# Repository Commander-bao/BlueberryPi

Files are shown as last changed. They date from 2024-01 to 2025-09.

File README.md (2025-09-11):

<h1 align="center">造“派”计划</h1>
<div align="center">








</div>

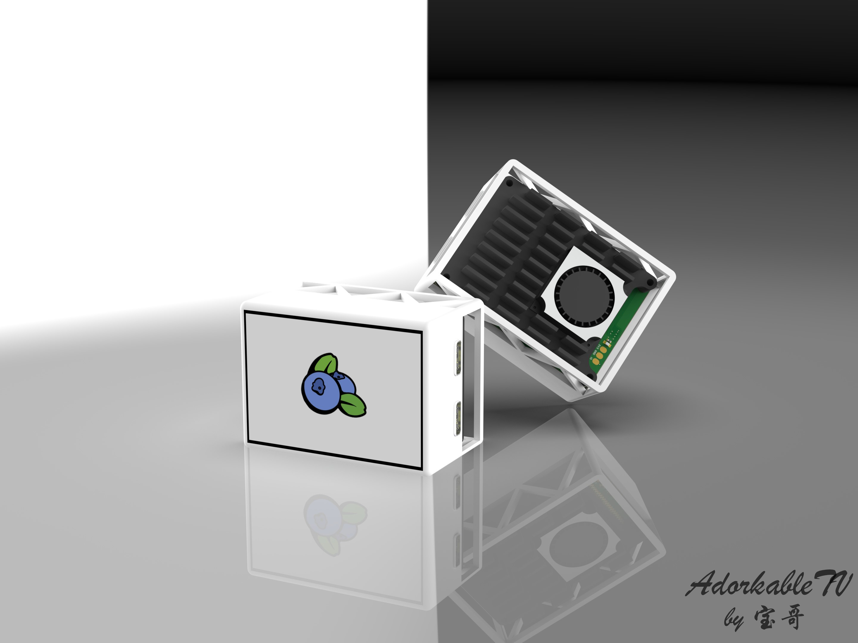
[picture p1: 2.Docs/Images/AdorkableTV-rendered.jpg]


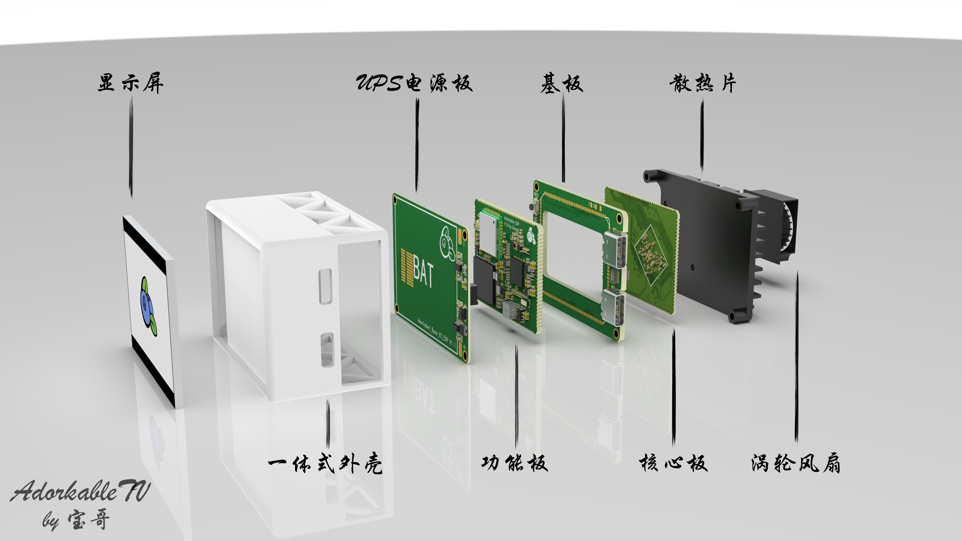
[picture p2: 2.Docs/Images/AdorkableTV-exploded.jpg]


从左至右分别为AdorkableTV、BlueberryPi 1、BlueberryPi-Core


## 0.关于本项目

当我看到树莓派4b的那一刻起，我就对这个卡片大小的单板计算机深深的吸引，漂亮的布局、完整的功能...我能不能自己也做一个呢？  

这就是造“派”计划的由来。本人通过四处搜寻资料以及在[这个项目](https://oshwhub.com/logicworld/h6_board)的指引下，成功设计出**BlueberryPi 1**，又在自学Altium Designer后画了它的核心板**BlueberryPi-Core**。在蓝莓派成功后又以立创泰山派为原型，重构软硬件设计了**AdorkableTV**。  

我的“蓝莓派”是一板成功的，但是也免不了这一路上的曲折，中途因为短路等各种原因焊废了好几块板子，导致我一度怀疑人生。好在功夫不负有心人，当电源小灯亮起来，屏幕上出现Ubuntu界面的时候，我知道我成功了。  

## 1.硬件打样说明

电路板Gerber文件为Hardware文件夹下的zip压缩包，可以直接上传到嘉立创平台进行打样。  

- BlueberryPi 1、Adorkable_Base、Adorkable_EXP请使用嘉立创eda（专业版）打开。  

- BlueberryPi-Core、Adorkable_Core请使用Altium Designer打开。  

BlueberryPi 1请使用嘉立创3313阻抗，1.6mm板厚。  

Adorkabe_Core、Adorkable_EXP请使用嘉立创3313阻抗，1.2mm板厚；Adorkable_Base、Adorkable_Base_V2请使用嘉立创3313阻抗，1.6mm板厚。以上均选用免费20%阻抗管控，有半孔的请使用四边半孔工艺。  

Adorkable_Base_V2_EXP为0.8mm板厚。

## 2.镜像烧录说明

BlueberryPi 1目前使用的是香橙派官方的镜像文件[这是网址](http://www.orangepi.cn/html/hardWare/computerAndMicrocontrollers/details/Orange-Pi-3-LTS.html)（蓝莓版镜像待移植）。下载好镜像后可以使用balenaEtcher将镜像烧录至TF卡中。  

AdorkableTV目前使用的是我定制的Ubuntu镜像，有xfce和xfce-full两个版本，可以从[百度网盘](https://pan.baidu.com/s/1jsw3okSnh8e9oXT7oVLvJg?pwd=v6qs)中下载使用。下载好镜像后使用瑞芯微烧录工具下载到板载EMMC中。

如果要为立创泰山派定制Ubuntu镜像，请参考Script文件夹下的README文档制作文件系统，将官方提供的镜像文件通过RKDevTool解包后替换boot.img和rootfs.img（建议修改分区表文件，扩大rootfs分区容量），最后通过RKDevTool文件夹下的打包脚本打包。也可以从百度网盘下载使用我移植的蓝莓版Ubuntu20.04桌面系统，Bootloader和Kernel已经放在了对应的文件夹下，大家可以根据需要下载。下载好镜像后可以使用balenaEtcher将镜像烧录至TF卡中，也可使用瑞芯微烧录工具下载到板载EMMC中。 

## 3.硬件使用说明

- BlueberryPi 1使用说明：将烧录好镜像文件的TF卡插入TF卡槽内，micro-usb接通5V-2A的电源后即可通过串口/HDMI连接使用。  

- BlueberryPi-Core使用说明：参考全志官方/香橙派/BlueberryPi 1中的原理图，绘制底板后，将BlueberryPi-Core贴至底板上使用（待测试）。  

- AdorkableTV使用说明：绘制扩展底板，将核心板和功能板分别贴至底板两面，烧录镜像至TF卡或EMMC中使用。

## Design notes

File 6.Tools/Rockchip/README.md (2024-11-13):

# 造“派”计划
## 工具说明
DriverAssistant —— 瑞芯微驱动安装助手  
Linux_Pack_Firmware —— Linux镜像打包工具  
RKDevTool_Release —— 瑞芯微烧录工具

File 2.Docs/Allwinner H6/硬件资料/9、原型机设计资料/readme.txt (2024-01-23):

H6_PRO_DDR3_1V1 是H6内部原型机的对应的原理图和PCB
注：PCB可以再设计中参考下，但原理图建议还是使用标案原理图设计（该原型机原理图前期设计存在大部分冗余设计和不合理设计，仅供参考，不建议直接使用）

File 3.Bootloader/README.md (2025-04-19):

# 造“派”计划

## 文件夹说明

Rockchip RK3566 tspi文件夹下为立创泰山派编译好的U-boot，详细内容请查看7.Script/Ubuntu文件夹内的README文档  

AdorkableTV文件夹下为AdorkableTV专用的U-boot

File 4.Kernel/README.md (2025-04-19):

# 造“派”计划

## 文件夹说明

Rockchip RK3566 tspi文件夹下为立创泰山派编译好的Kernel，详细内容请查看7.Script/Ubuntu文件夹内的README文档  

AdorkableTV文件夹下为AdorkableTV专用的Kernel以及部分修改过的内核源码

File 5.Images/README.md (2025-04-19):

# 造“派”计划
## 蓝莓版Ubuntu镜像
通过网盘分享的文件：BlueberryPi  
链接: https://pan.baidu.com/s/1jsw3okSnh8e9oXT7oVLvJg?pwd=v6qs 提取码: v6qs  

自己构建的方法请查看7.Script/Ubuntu文件夹内的README文档

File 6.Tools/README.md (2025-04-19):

# 造“派”计划

## 文件夹说明

Rockchip文件夹下为瑞芯微官方提供的部分工具

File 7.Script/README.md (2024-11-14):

# 造“派”计划

## 文件夹说明

Ubuntu文件夹下为Ubuntu根文件系统的构建脚本，详细内容请查看Ubuntu文件夹内的README文档

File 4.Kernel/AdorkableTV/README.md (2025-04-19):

# 造“派”计划
编译方法参考立创泰山派的教程：https://wiki.lckfb.com/zh-hans/tspi-rk3566/sdk-compilation/linux-compilation.html  

boot.img文件为编译好的kernel  

SDK文件夹内为基于立创泰山派修改过的部分SDK源码

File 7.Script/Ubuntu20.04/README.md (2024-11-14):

# 造“派”计划

## 简介

为瑞芯微系列芯片移植Ubuntu文件系统的脚本，魔改自鲁班猫（ https://github.com/LubanCat/ubuntu ）

## 适用板卡

- 使用RK3566处理器的板卡
- 使用RK3568处理器的板卡
- 使用RK3588处理器的板卡

## 安装依赖

推荐使用Ubuntu20.04及以上版本主机构建根文件系统

```
sudo apt-get install binfmt-support qemu-user-static
sudo dpkg -i ubuntu-build-service/packages/*
sudo apt-get install -f
```

## 构建 Ubuntu20.04镜像（仅支持64bit）

- lite：控制台版，无桌面
- xfce：桌面版，使用xfce桌面套件
- xfce-full：桌面版，使用xfce桌面套件+更多推荐软件包
- gnome：桌面版，使用gnome桌面套件
- gnome-full：桌面版，使用gnome桌面套件+更多推荐软件包

#### step1.构建基础 Ubuntu 系统。

```
# 运行以下脚本，根据提示选择要构建的版本
./mk-base-ubuntu.sh
```
#### step2.添加 rk overlay 层,并打包ubuntu-rootfs镜像

```
# 运行以下脚本，根据提示选择要构建处理器版本和ubuntu的版本
./mk-ubuntu-rootfs.sh
```

## 定制化说明

### 1.开机桌面壁纸设置：  

默认桌面壁纸为蓝莓派logo  

如要更改，请在/usr/share/xfce4/backdrops/目录下添加壁纸图片，并将mk-ubuntu-rootfs.sh文件下的blueberry_wallpaper.png替换为自己的壁纸图片

### 2.开机终端输出logo设置：  

默认输出图像为蓝莓派logo和BlueberryPi  

如要更改，请在/overlay/etc/update-motd.d/目录下更改00-header和10-help-text文件

### 3.主机名设置：  

默认主机名为BlueberryPi  

如要更改，请在mk-base-ubuntu.sh将`HOST=`后面的内容替换成你设置的主机名

### 4.用户名密码设置：  

默认用户名为blueberry，密码为pi；超级用户root，密码为root  

如要更改，请在mk-base-ubuntu.sh将全部`blueberry`换成你设置的用户名

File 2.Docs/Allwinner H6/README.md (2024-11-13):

# 造“派”计划
## 全志H6资料下载链接
> 百度网盘：[全志科技 Allwinnertech H6 SoC 方案级参考指南]  
> https://pan.baidu.com/s/1z1sYXkeuYGrHgMcpjg0E-Q?pwd=2dmb 提取码：2dmb

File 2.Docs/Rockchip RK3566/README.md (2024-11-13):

# 造“派”计划
## 泰山派参考资料
> 百度网盘：https://pan.baidu.com/s/18B0r1MrG7kCVOC_toQY16A?pwd=v5fz 提取码：v5fz  
> 夸克网盘：https://pan.quark.cn/s/b4261bc38992 提取码：qNT3
## 泰山派SDK
> 百度网盘：https://pan.baidu.com/s/1frwvXAGoHnPuEoVkOJ-2pA?pwd=jf9v 提取码: jf9v  
> 夸克网盘：https://pan.quark.cn/s/7b0fdc54c332 提取码：2fS5
## 泰山派系统镜像
> 百度网盘：https://pan.baidu.com/s/1Mc7N6GKHTd2zJTfLsGBSqw?pwd=af1y 提取码: af1y  
> 夸克网盘：https://pan.quark.cn/s/3b5cf0e118bd 提取码：RyR4
## 泰山派开发工具
> 百度网盘：https://pan.baidu.com/s/1-gNeeTlJgmgm2x1DpDAdRQ?pwd=v72h 提取码: v72h  
> 夸克网盘：https://pan.quark.cn/s/8b7a1f409af1 提取码：yNRw

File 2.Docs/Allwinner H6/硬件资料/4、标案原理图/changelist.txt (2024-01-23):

changelist：
/*************************************2017-7-20*************************************/
SOC1页
1：sdio clk CC2电容 容值改为5PF

SOC2页
2：在GPU 和 SYS 滤波电容 添加10uf电容 CC62 22uf电容 CC63

3：删除OSC 24M晶振

4：VCC18-HDMI添加4.7UF 电容 CC61

POWER页
5：分离CLDO1 和 ALDO3 将ALDO3的电源分配给DDR4

6：删除SWIN 和 SWOUT的电容 CP14 CP15

7：修改DCXOVCCIO的供电为BLDO3

USB页
8：修改电阻RU3 为4.3K

AV页
9：优化了运放电路，删除了多余器件

HDMI页
10：修改5V到地ESD为电容CH2

11：删除电阻RH10 RH11，RH5 改为1K.

12：修改DDC_EN电路，删除CEC的控制

WIFI+BT页
13：sdio clk 添加上拉电阻RW49

14：添加电源说明表格

GMAC页
15：添加GMAC页
添加电源网络VCC3V3_MAC 和 PD口部分出线

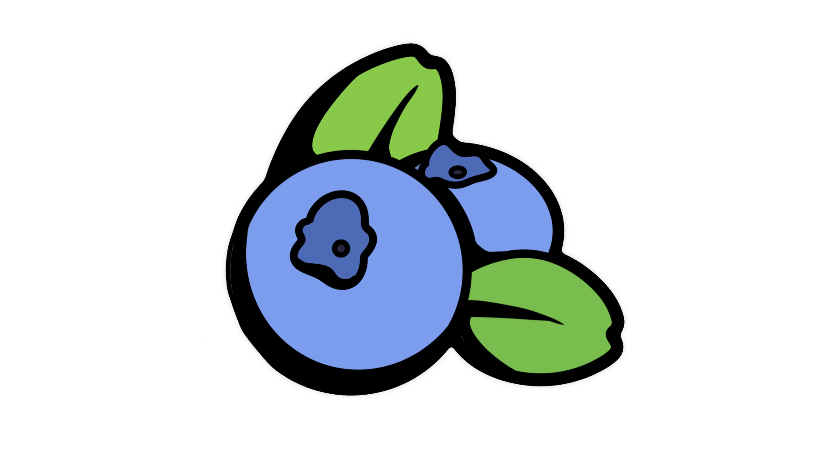
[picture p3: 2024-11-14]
7.Script/Ubuntu20.04/overlay/usr/share/xfce4/backdrops/blueberry_wallpaper.png

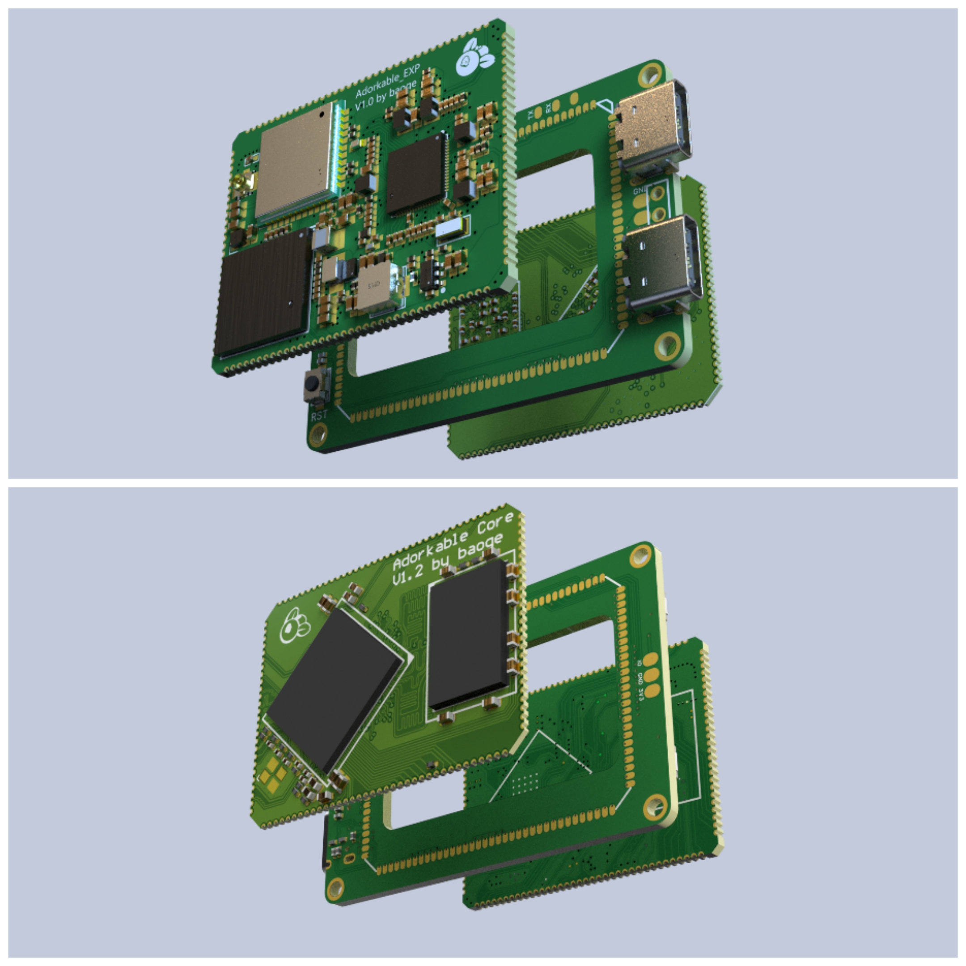
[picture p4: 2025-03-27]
2.Docs/Images/AdorkableTV.jpg

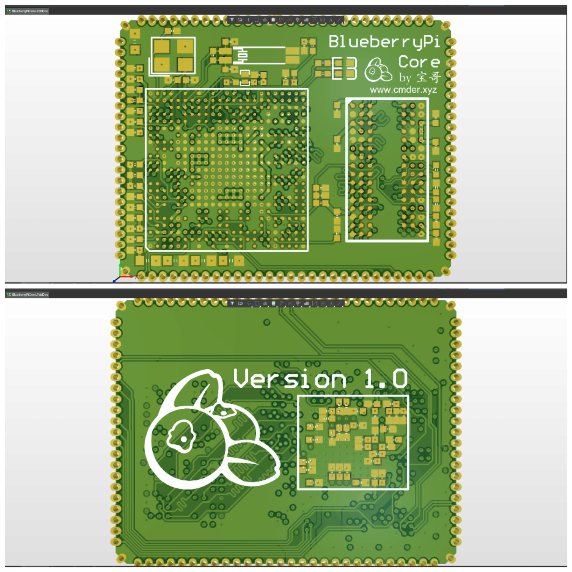
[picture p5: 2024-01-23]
2.Docs/Images/BlueberryPi-Core.jpg

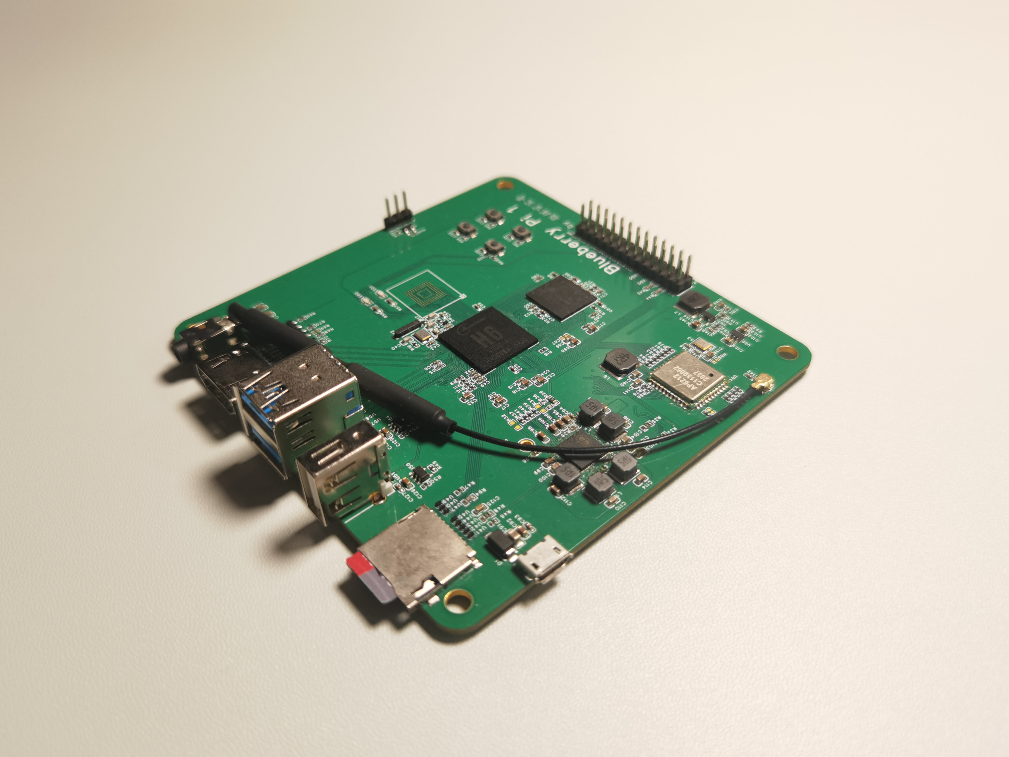
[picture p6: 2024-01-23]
2.Docs/Images/BlueberryPi 1.jpg

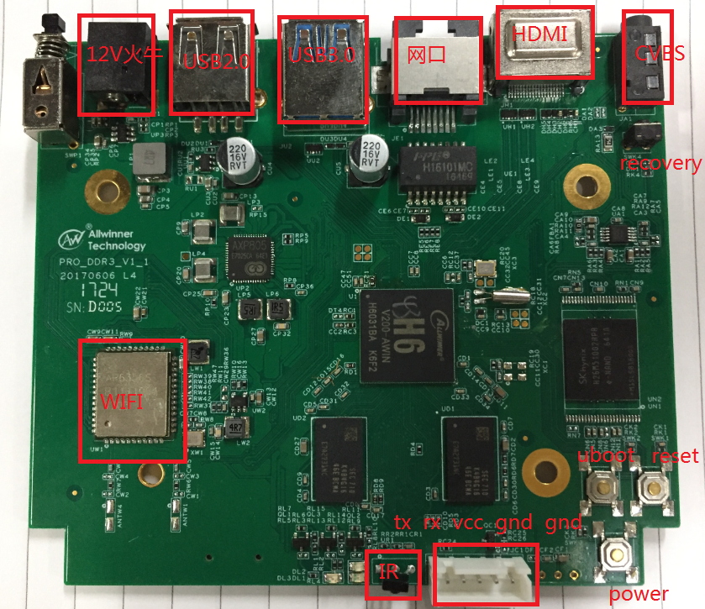
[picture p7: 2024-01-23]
2.Docs/Allwinner H6/硬件资料/8、DEMO板图示/原型机demo.PNG

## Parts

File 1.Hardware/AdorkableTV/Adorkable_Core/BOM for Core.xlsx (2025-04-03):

Comment | Description | Designator | Footprint | LibRef | Quantity | Value
C0402 | Capacitor | C1, C2, C51, C52, C53, C54, C55, C56, C62, C63, C64, C65, C66, C67, C68, C69, C70, C71, C72, C73, C74, C75, C76, C77, C82, C83, C84, C85, C86, C87, C88, C89, C90, C91, C92, C93, C94, C95, C96, C97, C98, C99 | CAP_0402 | Cap_0402 | 42 | 100nF
C0402 | Capacitor | C3, C4 | CAP_0402 | Cap_0402 | 2 | 12pF
C0201 | Capacitor | C5, C6, C7, C8, C9, C10, C12, C13, C15, C17, C18, C19, C20, C23, C24, C26, C28, C30, C31, C33, C34, C35, C38, C39, C40, C43, C46, C47, C48, C57, C104, C105, C106, C113, C118, C122 | CAP_0201 | Cap_0201 | 36 | 100nF
C0402 | Capacitor | C11, C14, C22, C25, C29, C61, C81 | CAP_0402 | Cap_0402 | 7 | 1uF
C0201 | Capacitor | C16, C32 | CAP_0201 | Cap_0201 | 2 | 1uF
C0402 | Capacitor | C21, C27, C36, C37, C41, C42, C100, C107, C108, C109, C114 | CAP_0402 | Cap_0402 | 11 | 4.7uF
C0402 | Capacitor | C44, C45 | CAP_0402 | Cap_0402 | 2 | 1nF
C0603 | Capacitor | C49, C50, C59, C60, C79, C80, C110, C115, C119 | CAP_0603 | Cap_0603 | 9 | 10uF
C0603 | Capacitor | C58, C78, C101, C102, C103, C111, C112, C116, C117, C120, C121 | CAP_0603 | Cap_0603 | 11 | 22uF
R0402 | Resistor | R1, R6, R9, R13 | RES_0402 | Res_0402 | 4 | 22Ω
R0402 | Resistor | R2 | RES_0402 | Res_0402 | 1 | 1MΩ
R0402 | Resistor | R3, R10 | RES_0402 | Res_0402 | 2 | 10K
R0402 | Resistor | R4, R5 | RES_0402 | Res_0402 | 2 | 2.2K
R0402 | Resistor | R7 | RES_0402 | Res_0402 | 1 | 1.62K
R0402 | Resistor | R8 | RES_0402 | Res_0402 | 1 | 120Ω
R0402 | Resistor | R11, R12 | RES_0402 | Res_0402 | 2 | 240Ω
R0402 | Resistor | R15 | RES_0402 | Res_0402 | 1 | 15K
RK3566 |  | U1 | RK3566 | RK3566 | 1
LPDDR4 |  | U2 | LPDDR4 | LPDDR4 | 1
24MHz |  | X1 | OSC-SMD_4P-L3.2-W2.5-BL | XL2EL89COI-111YLC-24M | 1

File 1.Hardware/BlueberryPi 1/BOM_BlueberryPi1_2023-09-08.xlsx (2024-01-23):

No. | Quantity | Comment | Designator | Footprint | Value | Supplier Part
1 | 1 | PJ-327C-4A | AUDIO1 | AUDIO-SMD_PJ-327C-4A |  | C145813
2 | 62 | 100nF | C1,C2,C3,C4,C5,C6,C12,C15,C16,C21,C22,C26,C27,C29,C30,C34,C35,C43,C45,C46,C47,C48,C49,C51,C53,C54,C55,C56,C57,C58,C59,C62,C63,C64,C65,C70,C71,C72,C81,C82,C83,C84,C85,C86,C87,C88,C90,C93,C120,C121,C122,C123,C124,C127,C128,C130,C133,C134,C138,C146,C150,C153 | C0402 | 100nF | C56392
3 | 3 | 1nF | C7,C8,C94 | C0402 | 1nF | C106205
4 | 18 | 1uF | C9,C11,C13,C14,C19,C20,C24,C25,C28,C32,C50,C61,C78,C79,C80,C89,C96,C147 | C0402 | 1uF | C52923
5 | 12 | 4.7uF | C10,C31,C38,C95,C102,C103,C104,C136,C137,C140,C141,C152 | C0603 | 4.7uF | C69335
6 | 32 | 10uF | C17,C18,C23,C33,C37,C60,C77,C92,C97,C98,C99,C100,C101,C105,C106,C107,C108,C109,C111,C112,C113,C114,C115,C116,C117,C118,C126,C129,C131,C139,C145,C149 | C0603 | 10uF | C344022
7 | 2 | 12pF | C39,C40 | C0603 | 12pF | C38523
8 | 2 | 7pF | C41,C42 | C0603 | 7pF | C1682
9 | 1 | 220nF | C44 | C0402 | 220nF | C192432
10 | 1 | 4.7uF | C52 | C0402 | 4.7uF | C77004
11 | 2 | NC-10uF | C66,C74 | C0603 | 100nF
12 | 2 | NC-1uF | C67,C75 | C0402 | 100nF
13 | 4 | NC-100nF | C68,C69,C73,C76 | C0402 | 100nF
14 | 1 | 22uF | C91 | C0805 | 22uF | C602037
15 | 3 | 100nF | C110,C125,C151 | C0603 | 100nF | C30926
16 | 1 | 2.2uF | C119 | C0402 | 2.2uF | C170151
17 | 1 | 4.7nF | C132 | C0402 | 4.7nF | C1538
18 | 1 | 470nF | C135 | C0402 | 470nF | C92361
19 | 1 | 10pF | C142 | C0402 | 10pF | C1545
20 | 2 | 18pF | C143,C144 | C0402 | 18pF | C1549
21 | 1 | 22pF | C148 | C0402 | 22pF | C1555
22 | 1 | TF-01A | CARD1 | TF-SMD_TF-01A |  | C91145
23 | 1 | KH-HDMI-19P-Cu | CN1 | HDMI-SMD_KH-HDMI-19P-CU |  | C709361
24 | 1 | SMAJ5.0A | D1 | SMA_L4.3-W2.6-LS5.0-RD |  | C908198
25 | 3 | AZ1045-04F.R7G | D2,D3,D4 | DFN2510-10_L2.5-W1.0-P0.50-BL |  | C356811
26 | 2 | 1N5819WS | D5,D6 | SOD-323_L1.8-W1.3-LS2.5-RD |  | C191023
27 | 1 | PM254V-11-03-H85 | H1 | HDR-TH_3P-P2.54-V-F |  | C541850
28 | 1 | U.FL-R-SMT-1(80) | JP1 | RF-SMD_FRF05002-JSS103M |  | C88374
29 | 5 | 1.5uH | L1,L2,L3,L4,L5 | IND-SMD_L4.0-W4.0 | 1.5uH | C42100
30 | 2 | 4.7uH | L6,L7 | IND-SMD_L6.0-W6.0_FNR60XXS | 4.7uH | C168008
31 | 2 |  | LED1,LED2 | LED_0603
32 | 4 | BSN20 | Q1,Q2,Q3,Q4 | SOT-23-3_L2.9-W1.6-P1.90-LS2.8-BR |  | C116157
33 | 3 | 33Ω | R1,R2,R94 | R0603 | 33Ω | C23140
34 | 11 | 0Ω | R3,R16,R37,R41,R55,R63,R64,R68,R76,R87,R93 | R0402 | 0Ω | C17168
35 | 25 | 10kΩ | R4,R11,R13,R15,R42,R43,R46,R49,R51,R53,R56,R62,R65,R66,R70,R77,R78,R79,R80,R81,R82,R83,R84,R85,R86 | R0402 | 10kΩ | C25744
36 | 6 | 1kΩ | R5,R12,R59,R60,R61,R90 | R0402 | 1kΩ | C11702
37 | 1 | 33Ω | R7 | R0402 | 33Ω | C25105
38 | 1 | 6.04kΩ | R8 | R0402 | 6.04kΩ | C2692942
39 | 8 | 2kΩ | R9,R10,R20,R21,R23,R38,R39,R40 | R0402 | 2kΩ | C4109
40 | 2 | 150kΩ | R14,R91 | R0402 | 150kΩ | C25755
41 | 1 | 0402WGF1005TCE | R17 | R0402 | 10K | C26082
42 | 2 | 240Ω | R18,R19 | R0402 | 240Ω | C25094
43 | 1 | 1.5kΩ | R22 | R0402 | 1.5kΩ | C25867
44 | 1 | 100Ω | R24 | R0402 | 100Ω | C25076
45 | 4 | 0Ω | R26,R33,R35,R48 | R0603 | 0Ω | C21189
46 | 3 | NC-0Ω | R32,R34,R36 | R0603 | NC-0Ω | C21189
47 | 2 | 2kΩ | R44,R45 | R0603 | 2kΩ | C22975
48 | 1 | 47kΩ | R47 | R0402 | 47kΩ | C25792
49 | 3 | 6.8kΩ | R50,R52,R54 | R0402 | 6.8kΩ | C25917
50 | 2 | 330Ω | R57,R58 | R0603 | 330Ω | C23138
51 | 2 | 1.8kΩ | R67,R71 | R0402 | 1.8kΩ | C25871
52 | 1 | NC | R69 | R0402 | 10K
53 | 2 | 56kΩ | R72,R73 | R0402 | 56kΩ | C25796
54 | 1 | 100kΩ | R75 | R0402 | 100kΩ | C25741
55 | 2 | NC-100kΩ | R88,R89 | R0402 | 100kΩ | C25741
56 | 1 | 33kΩ | R92 | R0402 | 33kΩ | C25779
57 | 4 | TS342A2P-WZ | SW1,SW2,SW3,SW4 | SW-SMD_L4.0-W2.9-LS5.0 |  | C557591
58 | 1 |  | U1 | BGA451_ALLWINNER_H6
59 | 21 |  | U4,U25,U40,U41,U42,U43,U44,U45,U47,U49,U51,U52,U55,U56,U57,U58,U59,U60,U61,U62,U63 | DFN1006-2L_L1.0-W0.6-P0.70-BI |  | C2936977
60 | 1 | MTP125-1213S1 | U7 | HDR-TH_26P-P2.54-V-M-R2-C13-S2.54 |  | C358701
61 | 1 | K4E6E304EC-EGCG | U35 | FBGA-178_L11.5-W11.0_K4E6E304EC-TL |  | C2803256
62 | 1 |  | U37 | QFN-56_L7.0-W7.0-P0.40-TL-EP4.6
63 | 1 | TP-红色测试点 | U38 | TESTPOINT-TH_BD3.2 |  | C9900007423
64 | 1 | KLMAG1JETD-B041 | U39 | FBGA-153_L13.0-W11.5-P0.50_KLMAG1JETD-B041 |  | C499919
65 | 3 | SY6280AAC | U50,U53,U54 | SOT-23-5_L3.0-W1.7-P0.95-LS2.8-BL |  | C55136
66 | 1 | 2.4GHz | U64 | QFN-44_L12.0-W12.0-P0.90-TL_AP6212 | 2.4GHz | C2798300
67 | 1 | SY8089A1AAC | U65 | TSOT-23-5_L2.9-W1.6-P0.95-LS2.8-BR |  | C479074
68 | 1 | ME6212C18M5G | U66 | SOT-23-5_L3.0-W1.7-P0.95-LS2.8-BL |  | C236669
69 | 1 | U-F-M5DS-Y-1 | USB1 | MICRO-USB-SMD_U-F-M5DS-Y-1 |  | C106818
70 | 1 | 906-162A1011D10200 | USB2 | USB-A-TH_4P-P1.40-V-F-C39416 |  | C39417
71 | 1 | USB-303WSD-BRY | USB3 | USB-A-TH_XUNPU_USB-303WSD-BRY |  | C2895028
72 | 1 | 24MHz | X1 | CRYSTAL-SMD_4P-L3.2-W2.5-BL | 24MHz | C70590
73 | 1 | 32.768kHz | X2 | MC-146_4P-L6.7-W1.5-P0.85-TL | 32.768kHz | C94977
74 | 1 | 26MHz | X3 | CRYSTAL-SMD_4P-L3.2-W2.5-BL | 26MHz | C164050

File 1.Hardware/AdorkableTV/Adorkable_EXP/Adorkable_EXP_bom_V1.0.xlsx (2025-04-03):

No. | Quantity | Comment | Designator | Footprint | Value | Supplier Part
1 | 12 | 100nF | C98,C103,C151,C153,C154,C225,C226,C227,C228,C230,C231,C234 | R0402 | 100nF | C307331
2 | 9 | 10uF | C99,C113,C115,C123,C128,C132,C133,C134,C136 | C0603 | 10uF | C19702
3 | 5 | 100nF | C100,C102,C262,C267,C269 | R0603 | 100nF | C14663
4 | 1 | 22pF | C101 | R0402 | 22pF | C1555
5 | 12 | 22uF | C104,C105,C112,C114,C127,C131,C135,C155,C156,C158,C159,C160 | C0603 | 22uF | C59461
6 | 2 | 10uF | C106,C139 | R0402 | 10uF | C15525
7 | 25 | 1uF | C107,C108,C109,C110,C111,C116,C117,C118,C119,C120,C121,C122,C124,C125,C126,C129,C130,C137,C138,C144,C145,C146,C147,C157,C162 | R0402 | 1uF | C14445
8 | 2 | 12pF | C140,C143 | R0402 | 12pF | C1547
9 | 1 | 4.7uF | C141 | R0402 | 4.7uF | C307423
10 | 2 | 680pF | C148,C149 | R0402 | 680pF | C1541
11 | 1 | 100nF | C150 | R0402 | 100nF | C1525
12 | 1 | 27pF | C152 | R0402 | 27pF | C1557
13 | 3 | 4.7uF | C229,C232,C268 | R0402 | 4.7uF | C368809
14 | 1 | 2.2uF | C233 | R0402 | 2.2uF | C12530
15 | 1 | 10pF | C261 | C0402 | 10pF | C513681
16 | 1 | 1uF | C263 | R0603 | 1uF | C1592
17 | 2 | 12pF | C264,C265 | C0603 | 12pF | C107034
18 | 1 | 1uF | C266 | R0402 | 1uF | C52923
19 | 1 | 3.3uH | L2 | IND-SMD_L4.4-W4.2 | 3.3uH | C408336
20 | 5 | 470nH | L3,L4,L5,L6,L7 | IND-SMD_L2.0-W1.6_MHCHL201610A-1R0M-Q8A | 470nH | C375941
21 | 1 | BLM15AG121SN1D | L8 | L0402 |  | C85812
22 | 2 | BLM18PG181SN1D | L9,L10 | L0603 |  | C82850
23 | 1 | 240nH | L11 | IND-SMD_L2.5-W2.0_WPN252012H | 240nH | C305274
24 | 1 | 4.7uH | L16 | L1008 | 4.7uH | C91237
25 | 1 | 19-217/GHC-YR1S2/3T | LED1 | LED0603-RD |  | C72043
26 | 2 | 47kΩ | R36,R44 | R0402 | 47kΩ | C25792
27 | 1 | 232kΩ | R37 | R0402 | 232kΩ | C309542
28 | 2 | 4.7kΩ | R39,R108 | R0402 | 4.7kΩ | C25900
29 | 1 | 51kΩ | R40 | R0402 | 51kΩ | C25794
30 | 4 | 0402WGF1000TCE | R41,R42,R43,R54 | R0402 |  | C25076
31 | 1 | 120kΩ | R45 | R0402 | 120kΩ | C25750
32 | 1 | 180kΩ | R48 | R0402 | 180kΩ | C138046
33 | 5 | 10kΩ | R49,R52,R84,R85,R86 | R0402 | 10kΩ | C71617
34 | 1 | 56kΩ | R51 | R0402 | 56kΩ | C25796
35 | 1 | 0402WGF5102TCE | R53 | R0402 |  | C25794
36 | 1 | 22Ω | R57 | R0402 | 22Ω | C25092
37 | 1 | 10kΩ | R106 | R0402 | 10kΩ | C25744
38 | 1 | 0Ω | R107 | R0402 | 0Ω | C17168
39 | 1 | 30kΩ | R122 | R0402 | 30kΩ | C138008
40 | 1 | BWIPX-1-001E | RF1 | IPEX-SMD_BWIPX-1-001E |  | C496552
41 | 1 | SY8113BADC | U2 | TSOT-23-6_L2.9-W1.6-P0.95-LS2.8-BR |  | C78989
42 | 1 | TCS4525_WT | U3 | TCS4525
43 | 1 | SDINBDG4-8G | U6 | FBGA-153_L13.0-W11.5-P0.50_KLMAG1JETD-B041 |  | C577444
44 | 1 | 2.4GHz | U15 | QFN-44_L12.0-W12.0-P0.90-TL_AP6212 | 2.4GHz | C2798300
45 | 1 | RK809-5 | U21 | RK809-5
46 | 1 | 32.768kHz | X2 | CRYSTAL-SMD_L3.2-W1.5-1 | 32.768kHz | C5213671
47 | 1 | 26MHz | X3 | CRYSTAL-SMD_4P-L2.0-W1.6-BL | 26MHz | C255886

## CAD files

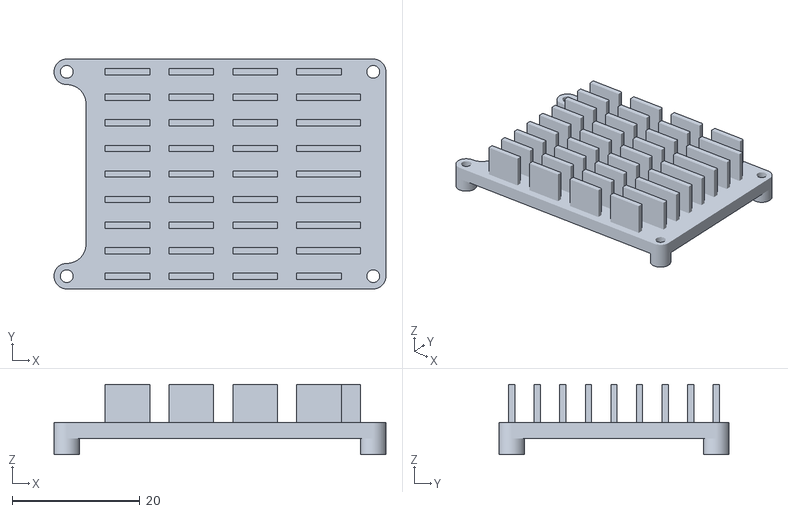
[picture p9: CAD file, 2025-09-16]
8.Model/AdorkableTV被动散热片.stl
52.0 x 36.0 x 11.0

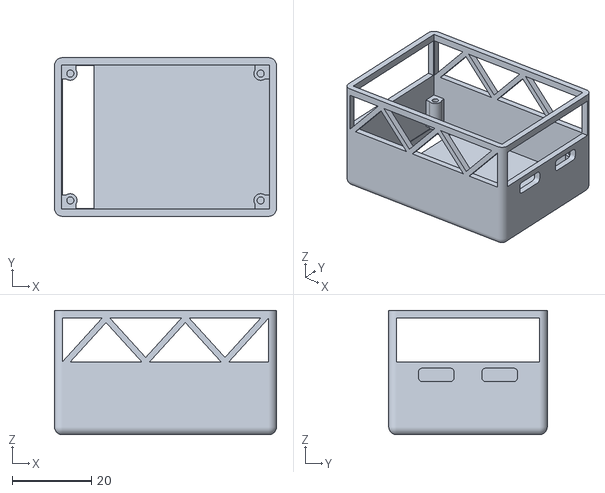
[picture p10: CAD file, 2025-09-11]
8.Model/AdorkableTV外壳.stl
56.0 x 40.0 x 31.4

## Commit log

2024-01-23 上传蓝莓派硬件部分
    [BOM_BlueberryPi1_2023-09-08.xlsx, BlueberryPi-Core.PrjPcb, Core.SchDoc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]
2024-01-23 上传芯片文档
    [H6_DDR3_2X16_V1_0.DSN, H6_DDR3_2X16_V1_0.brd, H6_PRO_DDR3_V1_1-PCB加工工艺要求说明书.xls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]
2024-01-23 上传项目
    [H6_DDR3_2X16_V1_0.DSN, H6_DDR3_2X16_V1_0.brd, H6_PRO_DDR3_V1_1-PCB加工工艺要求说明书.xls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]
2024-01-23 上传图片
2024-11-13 更新目录结构、文档手册及泰山派RK3566部分相关资料
    [H6_DDR3_2X16_V1_0.DSN, H6_DDR3_2X16_V1_0.brd, H6_PRO_DDR3_V1_1-PCB加工工艺要求说明书.xls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]
2024-11-14 上传RK3566构建Ubuntu文件系统脚本并更新文档
2024-11-14 更新Tools文件夹说明
2024-11-14 更新Kernel文件夹说明
2024-11-14 更新Bootloader文件夹说明
2024-11-20 修改文件夹名称
2024-11-20 增加startx配置文件
2025-03-25 上传AdorkableTV源文件
2025-03-25 上传AdorkableTV核心板源文件
2025-03-27 上传Gerber文件
2025-03-27 更新README
2025-03-27 上传logo
2025-04-02 修改README
2025-04-03 更新AdorkableTV的Kernel与U-boot
2025-04-03 上传AdorkableTV核心板BOM表和坐标文件
    [BOM for Core.xlsx, Pick Place for Core.csv]
2025-04-03 上传AdorkableTV功能板Gerber文件并修正错误
2025-04-03 上传AdorkableTV功能板BOM与坐标文件
    [Adorkable_EXP_PickAndPlace_V1.0.csv, Adorkable_EXP_bom_V1.0.xlsx]
2025-04-03 更新README中的硬件打样说明
2025-04-06 上传完整镜像链接
2025-04-08 上传AdorkableTV部分内核源码
2025-04-10 更新Kernel文件夹下的README
2025-04-13 上传Adorkable_Core的PCB工程源文件
    [Core.PrjPcb]
2025-06-22 上传Adorkable_Base_V2
2025-06-22 删除文件
2025-08-19 上传Adorkable_Base_V2_EXP
2025-08-29 优化Adorkable_Base_V2_EXP
2025-09-04 修正拼写错误
2025-09-04 上传渲染图并更新README
2025-09-11 上传AdorkableTV外壳文件
    [AdorkableTV外壳.stl]
2025-09-16 上传AdorkableTV被动散热片模型
    [AdorkableTV被动散热片.stl]
